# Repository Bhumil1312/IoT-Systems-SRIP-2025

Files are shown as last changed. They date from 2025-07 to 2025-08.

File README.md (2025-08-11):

# HubVolt & AtmoSync — Hardware & Firmware Resources







---

## System Architecture

### 📡 AtmoSync Architecture
The HubVolt system centers around an ESP32 microcontroller connected to a transistor-driven buck converter that enables or disables the USB hub's power supply. The firmware listens for TCP commands to activate or deactivate the USB Hub power. A web dashboard enables seamless control and configuration. Safety features such as emergency shutdown and Wi-Fi fallback modes ensure reliability.

AtmoSync Architecture

### 🔌 HubVolt Architecture
AtmoSync uses an ESP32 microcontroller interfaced with an SHT31 temperature and humidity sensor via I2C. It continuously displays data on an 8x32 LED matrix using the MAX7219 module and communicates the data to a central server via TCP or POST. The firmware includes dynamic AP+STA Wi-Fi configuration and sensor readouts periodically for live environmental tracking.

HubVolt Architecture

Both **HubVolt** and **AtmoSync** are ESP32-based IoT systems. HubVolt focuses on **USB hub power control**, while AtmoSync is a **temperature and humidity logger** with display capabilities. Each system uses a web-based configuration interface and communicates with a server for registration and command handling.

---

## Folder Structure

```
All files/
├── AtmoSync/
│   ├── Schematic_AtmoSync_v1/      # KiCAD or PDF schematic files for AtmoSync
│   ├── AtmoSync.svg                # Schematic as SVG image
│   ├── AtmoSync_v1.ino             # Arduino/ESP32 firmware source code
│   └── Gerber_AtmoSync_v1.zip      # Gerber files for PCB fabrication
|   └── AtmoSync Setup Guide        # Setup Guide for AtmoSync
├── HubVolt/
│   ├── Enclosure_design/           # 3D enclosure design files (STL/STEP/etc.)
│   ├── Schematic_HubVolt_v1/       # KiCAD or PDF schematic files for HubVolt
│   ├── Gerber_HubVolt_v1.0.zip     # Gerber files v1.0 for PCB, the version 1.0 uses adjustable Buck converter
│   ├── Gerber_HubVolt_v1.1.zip     # Gerber files v1.1 for PCB, the version 1.1 uses fixed voltage Buck converter
│   ├── HubVolt.svg                 # Schematic as SVG image
│   └── HubVolt_v1.ino              # Arduino/ESP32 firmware source code
|   └── HubVolt Setup Guide         # Setup Guide for HubVolt
└── readme.md                       # This documentation file
```

---

## Components List

### 🔧 AtmoSync Components

| Component | Quantity | Description |
|---|---|---|
| ESP32 Dev Board | 1 | Core microcontroller |
| SHT31 Sensor | 1 | Temperature & humidity sensor |
| MAX7219 Display Module | 1 | 8x32 LED Matrix (4-in-1) |
| Buck converter | 1 | step down DC power to 5v |

### 🔌 HubVolt Components

| Component | Quantity | Description |
|---|---|---|
| ESP32 Dev Board | 1 | Core microcontroller |
| Transistor (e.g., 2N2222) | 1 | Cntrolling switching power supply of USB HUB |
| Buck converter | 2 | step down DC power to 5v |
| USB Hub module | 1 | provide USB hub functionality |
---

## First-Time Setup Guide

To change saved WiFi or server configuration after initial setup:
- First, turn OFF the power supply to the device.
- Press and HOLD the **boot button**.
- Turn ON the power supply **while keeping the boot button pressed**.
- Hold for **at least 1 second**, then release.
- The device will now boot into configuration mode.

1. **Power the ESP32** with USB or 5V supply.
2. Press the **boot button** before power-on to clear saved WiFi & server config.
3. Connect to the Access Point: `ESP32-Setup` → Password: `configureme`
4. Open browser → navigate to `192.168.4.1`
5. Fill the configuration form:
   - Device Name (e.g., atmosync01 or hubvolt01)
   - WiFi SSID / Password
   - Server IP and Port
   - Auth method (Open / Personal / Enterprise)
6. Save → Device restarts → Connects to WiFi → Registers with server.

---

## Troubleshooting

### 🔁 Reconfiguration Instructions
If you want to change the WiFi and Server configuration parameters:
1. Turn off the device's power supply.
2. Press and hold the boot button.
3. While holding it, power on the device.
4. Keep it pressed for at least 1 second.
5. Release the button; the device will enter setup mode.

Then reconnect to `ESP32-Setup` WiFi and open `192.168.4.1` to reconfigure.

| Issue | Possible Cause | Solution |
|---|---|---|
| Device not visible on network | Wrong WiFi credentials | Reboot with boot button, reconfigure |
| Configuration page not loading | Not in AP mode | Check serial monitor for IP info |
| Data not displaying on matrix | Sensor error or no data | Check wiring; ensure SHT31 connected |
| Power not switching (HubVolt) | Relay not triggered | Check GPIO, circuit, or transistor bias|
| Device restarts unexpectedly | Server unreachable or crash | Verify IP, power stability, firmware |

---

## License & Credits

Developed during the **Summer Research Internship Program (SRIP)** at **IIT Gandhinagar**.

---

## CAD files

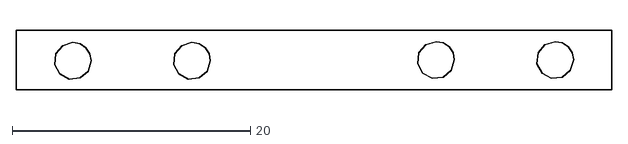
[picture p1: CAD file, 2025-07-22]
AtmoSync/Display Support.dxf
50.0 x 5.00

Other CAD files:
AtmoSync/AtmoSync_logo.dxf
HubVolt/Enclosure_design/AtmoSync_logo.dxf
HubVolt/Enclosure_design/HubVolt_logo.dxf

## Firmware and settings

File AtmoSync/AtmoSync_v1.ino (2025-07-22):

#include <WiFi.h>
#include <WebServer.h>
#include <Preferences.h>
#include <WiFiClient.h>
#include <esp_wpa2.h>
#include <Adafruit_SHT31.h>
#include <esp_wifi.h>
#include <Wire.h>
#include <MD_Parola.h>
#include <MD_MAX72xx.h>
#include <SPI.h>

//Define hardware type
#define HARDWARE_TYPE MD_MAX72XX::FC16_HW

//Define the number of connected devices
#define MAX_DEVICES 4

#define bootButtonPin 0 //Flash configuration of server
#define DATA_PIN 13 //DIN
#define CLK_PIN 14 //CLK
#define SDA_PIN 21 //SDA
#define SCL_PIN 22 //SCL
#define CS_PIN 27 //CS

typedef String string;

// Object declarations
Preferences powerAccessController;
WebServer configServer(80);
Adafruit_SHT31 sht31 = Adafruit_SHT31();
//Create a new instance of the MD_Parola class with custom SPI pins
MD_Parola myDisplay = MD_Parola(HARDWARE_TYPE, DATA_PIN, CLK_PIN, CS_PIN, MAX_DEVICES);

// Access Point credentials
const char* ApSSID = "ESP32-Setup";
const char* ApPassword = "configureme";

// Device Name
String device_name = "";


#define NUM_READINGS 60
#define READING_INTERVAL_MS 20
#define DISPLAY_INTERVAL_MS 60000

float temperatureReadings[NUM_READINGS];
float humidityReadings[NUM_READINGS];
int readingIndex = 0;
bool bufferFilled = false;

unsigned long lastReadingTime = 0;
unsigned long lastDisplayUpdate = 0;

float avgTemperature = 0;
float avgHumidity = 0;

// String Display for scrolling
String displaystr = "00.0C 00.0%RH";

// Web page handler
void handleRoot() {
  String html = R"(<script>function myFunction(){
                            var x = document.getElementById('password');
                            if (x.type === 'password') {x.type = 'text';} 
                            else {x.type = 'password';}}
                  </script>
                  <h2>AtmoSync (v1.0)</h2>
                  <p>Welcome to AtmoSync.</p>
                  <h3>WiFi & Server Configuration</h3>
                  <form action='/save' method='post'><table>
                  <tr>
                    <td>Device Name (It should not have any space & special characters):</td>
                    <td><input type='text' name='device_name'></td>
                  </tr>
                  <tr>
                    <td>SSID:</td>
                    <td><input type='text' name='ssid'></td>
                  </tr>
                  <tr>
                    <td>Connection-Type:</td> 
                    <td>
                      <select name='connection_type'>
                        <option value='Open'>Open</option>
                        <option value='Personal'>Personal</option>
                        <option value='Enterprise'>Enterprise</option>
                      </select>
                    </td>
                  </tr>
                  <tr>
                    <td>Username (Not needed for Open/Personal):</td>
                    <td><input type='username' name='username'></td>
                  </tr>
                  <tr>
                    <td>Password (Not needed for Open):</td> 
                    <td> <input type='password' name='password' id='password'><br>
                        <input type='checkbox' onclick='myFunction()'>Show Password
                    </td>
                  </tr>
                  <tr>
                    <td>Server IP:</td> 
                    <td> <input type='text' name='server_ip'></td>
                  </tr>
                  <tr>
                    <td>Server TCP Port:</td>
                    <td> <input type='text' name='server_port' ></td>
                  </tr>
                </table>
                <input type='submit' value='Save'>
                </form>)";
  configServer.send(200, "text/html", html);
}

bool isNumber(const string& s)
{
  if(s.length() <= 0) return false;
  for (char c : s) {
      if (!isdigit(c)) return false;
  }
  return true;
} 

void htmlError (const string& s){
  configServer.send(200, "text/html", "<h3>"+s+"</h3>");
  delay(5000);
  ESP.restart();
}

bool isValidIpAddress(const string& str) {
    if (str.isEmpty()) return false;

    int start = 0, end = str.indexOf('.', start);
    int count = 0;
    String str_temp; 

    while (end != -1) {
        str_temp = str.substring(start, end);
        if(!isNumber(str_temp)) return false;
        int num = str_temp.toInt();
        if(num < 0 || num > 255) return false;
        start = end + 1;
        end = str.indexOf('.', start);
        count = count + 1;
    }
    if (count != 3) return false;

    return true;
}

// Save form inputs to Preferences and restart
void handleSave() {
  String ssid;
  String connection_type;
  String username = "";
  String password = "";
  String server_ip;
  String server_port;

  if (!configServer.hasArg("device_name")) htmlError("Device name is not provided.");
  else device_name = configServer.arg("device_name");
  if (device_name.length() <= 0) htmlError("Device name is not provided.");

  if (!configServer.hasArg("ssid")) htmlError("SSID is not provided.");
  else ssid = configServer.arg("ssid");
  if (ssid.length() <= 0) htmlError("SSID is not provided.");

  if (!configServer.hasArg("connection_type")) htmlError("Connection-Type is not provided.");
  else connection_type = configServer.arg("connection_type");
  if (connection_type.length() <= 0) htmlError("Connection-Type is not provided.");

  if (connection_type != "Open" && !configServer.hasArg("password")) htmlError("Password expected and it is not provided.");
  else password = configServer.arg("password");
  if (connection_type != "Open" && (password.length() <= 0)) htmlError("Password expected and it is not provided.");

  if(connection_type == "Enterprise" && !configServer.hasArg("username")) htmlError("Username expected and it is not provided.");
  else username = configServer.arg("username");
  if (connection_type == "Enterprise" && (username.length() <= 0)) htmlError("Username expected and it is not provided.");

  if(!configServer.hasArg("server_ip")) htmlError("Server IP address is not provided.");
  else{
    server_ip = configServer.arg("server_ip");
    if (!isValidIpAddress(server_ip)) htmlError("Invalid Server IP address.");
  }

  if(!configServer.hasArg("server_port")) htmlError("Server port number is not provided.");
  server_port = configServer.arg("server_port");
  if(!isNumber(server_port)) htmlError("Invalid Server port number.");

  powerAccessController.begin("server-config", false);  
  powerAccessController.putString("device_name", device_name);
  powerAccessController.putString("ssid", ssid);
  powerAccessController.putString("connection_type", connection_type);
  powerAccessController.putString("username", username);
  powerAccessController.putString("password", password);
  powerAccessController.putString("server_ip", server_ip);
  powerAccessController.putString("server_port", server_port);
  powerAccessController.end();
  configServer.send(200, "text/html", "<h3>Configuration saved. Device is ready now.</h3>");
  delay(2000);
  ESP.restart();
}

//Start Access Point mode
void startAccessPointMode() {
  WiFi.mode(WIFI_AP);
  delay(1000);
  WiFi.softAP(ApSSID, ApPassword);

  Serial.println("Access Point mode started.");
  Serial.println(WiFi.softAPIP());

  configServer.on("/", handleRoot);
  configServer.on("/save", handleSave);
  configServer.begin();
}

String mac2String(byte ar[]) {
  String s;
  for (byte i = 0; i < 6; ++i)
  {
    char buf[3];
    sprintf(buf, "%02X", ar[i]);
    s += buf;
    if (i < 5) s += ':';
  }
  return s;
}

bool conveyIP_Port(const String& ip,const String& port){
  //Create a TCP client object
  WiFiClient client;
  uint8_t baseMac[6];
  esp_err_t ret = esp_wifi_get_mac(WIFI_IF_STA, baseMac);
  if (ret != ESP_OK) return false;

  //Attempt to connect to the server with given IP and port
  if(!client.connect(ip.c_str(), port.toInt())){
    Serial.println("Connection to host failed");
    return false;
  }

  Serial.println("Connection to host successful");
  String myIP = WiFi.localIP().toString();
  String payload = device_name + " " + myIP + " " + mac2String(baseMac);
  //HTTP POST request (plain text) because TCP client send raw TCP data
  String request = String("POST /atmosync/register HTTP/1.1\r\n") +
                  "Host: " + ip + ":" + port + "\r\n" +
                  "Content-Type: text/plain\r\n" +
                  "Content-Length: " + payload.length() + "\r\n" +
                  "Connection: close\r\n\r\n" +
                  payload;
  // Send the complete HTTP request to server
  client.print(request);
  client.stop();
  return true;
}

//Connect to WiFi using saved credentials
void connectToSavedWiFi() {
  powerAccessController.begin("server-config", true);
  device_name = powerAccessController.getString("device_name", "");
  String ssid = powerAccessController.getString("ssid", "");
  String connection_type = powerAccessController.getString("connection_type", "");
  String username = powerAccessController.getString("username", "");
  String password = powerAccessController.getString("password", "");
  String server_ip = powerAccessController.getString("server_ip", "");
  String server_port = powerAccessController.getString("server_port", "3000");

  powerAccessController.end();

  if (ssid.isEmpty()) {
    Serial.println("No saved WiFi credentials found. Starting AP mode...");
    startAccessPointMode();
    return;
  }
  
  WiFi.mode(WIFI_STA);
  if(connection_type == "Enterprise"){
    //WPA2-Enterprise configuration
    esp_wifi_sta_wpa2_ent_set_identity((uint8_t *)username.c_str(), strlen(username.c_str()));
    esp_wifi_sta_wpa2_ent_set_username((uint8_t *)username.c_str(), strlen(username.c_str()));
    esp_wifi_sta_wpa2_ent_set_password((uint8_t *)password.c_str(), strlen(password.c_str()));
    esp_wifi_sta_wpa2_ent_enable();
  }

  WiFi.begin(ssid.c_str(),(connection_type == "Personal")?password.c_str():"");
  Serial.println("Connecting to "+ssid);
  unsigned long startAttemptTime = millis();
  while (WiFi.status() != WL_CONNECTED && millis() - startAttemptTime < 15000) {
    Serial.print(".");
    delay(500);
  }
  if (WiFi.status() == WL_CONNECTED) {
    Serial.println("\nConnected to WiFi.");
    Serial.print("IP Address: ");
    Serial.println(WiFi.localIP());
    if(conveyIP_Port(server_ip, server_port) == false)  ESP.restart();
  }
  else {
    Serial.println("\nFailed to connect to WiFi. Restarting...");
    ESP.restart();
  }
}

void updateSensorReadings() {
  if (millis() - lastReadingTime >= READING_INTERVAL_MS) {
    lastReadingTime = millis();
    
    float temp = sht31.readTemperature();
    float hum = sht31.readHumidity();
    
    // Store in circular buffer
    temperatureReadings[readingIndex] = temp;
    humidityReadings[readingIndex] = hum;

    readingIndex = (readingIndex + 1) % NUM_READINGS;
    if (readingIndex == 0) bufferFilled = true;

    // Calculate moving average only if buffer filled
    if (bufferFilled) {
      float sumTemp = 0, sumHum = 0;
      for (int i = 0; i < NUM_READINGS; i++) {
        sumTemp += temperatureReadings[i];
        sumHum += humidityReadings[i];
      }
      avgTemperature = sumTemp / NUM_READINGS;
      avgHumidity = sumHum / NUM_READINGS;
    }
  }
}

String sense(const String& arg) {
  //Sense the temperature and format it to 1 decimal places
  String temperature = String(avgTemperature, 1) + "C";
  //Sense the humidity and format it to 1 decimal places
  String humidity = String(avgHumidity, 1) + "%RH";
  displaystr = temperature + " " + humidity;

  return device_name + " " + arg + " " + displaystr;
}

void handleServercommands() {
  if (configServer.method() == HTTP_POST) {
    String requestBody = configServer.arg("plain");
    Serial.println("Received POST body:");
    Serial.println(requestBody);

    if (requestBody.length() == 0) {
      configServer.send(400, "text/plain", "Error: Empty body");
      return;
    }

    int firstSpace = requestBody.indexOf(' ');
    if (firstSpace == -1) {
      configServer.send(400, "text/plain", "Error: Invalid command syntax");
      return;
    }

    String command = requestBody.substring(0, firstSpace);
    String argument = requestBody.substring(firstSpace + 1);
    
    argument.trim();

    if (command == "SENSE") configServer.send(200, "text/plain", sense(argument));
    else if (command == "ECHO") configServer.send(200, "text/plain", device_name + " " + argument);
    else configServer.send(400, "text/plain", "Error: Unknown command");
    return;
  }
}

void setup() {
  //Initializes SDA_PIN and SCL_PIN for I2C communication
  Wire.begin(SDA_PIN, SCL_PIN);

  Serial.begin(115200);
  delay(1000);

  pinMode(bootButtonPin, INPUT_PULLUP);

  int buttonState = digitalRead(bootButtonPin);
  if (buttonState == LOW) {
    Serial.println("Boot button is pressed");
    powerAccessController.begin("server-config", false);
    powerAccessController.clear();
    powerAccessController.end();
  }

  //Initialize the SHT31 sensor using the I2C address 0x44 (default)
  Serial.println("Initializing SHT31 sensor... ");
  
  //SHT31 sensor not found or fails to initialize
  if (!sht31.begin(0x44)) {
    Serial.println("SHT31 not found!");
    ESP.restart();
  }
  Serial.println("SHT31 initialized.");

  myDisplay.begin();
  myDisplay.setIntensity(0);    // Brightness (0-15)
  myDisplay.displayClear();     // Clear display

  connectToSavedWiFi();

  configServer.on("/",handleServercommands);
  configServer.begin();
}

void loop() {
  configServer.handleClient();

  updateSensorReadings();

  // Update display readings every 60 seconds and average available
  if (millis() - lastDisplayUpdate >= DISPLAY_INTERVAL_MS && bufferFilled) {
    lastDisplayUpdate = millis();
    displaystr = String(avgTemperature, 1) + "C " + String(avgHumidity, 1) + "%RH";
  }

  // Animate the current readings on display
  if (myDisplay.displayAnimate()) {
    myDisplay.displayClear();
    myDisplay.displayScroll(displaystr.c_str(), PA_RIGHT, PA_SCROLL_LEFT, 100);
  }
}
